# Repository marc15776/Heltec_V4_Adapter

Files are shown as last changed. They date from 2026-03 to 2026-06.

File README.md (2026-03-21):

# Heltec LoRa V4 Adapter

This is a fork from [kiu/lofence](https://github.com/kiu/lofence)

I used the the resistor and opamp concept to use  with the [Heltec LoRa V4](https://heltec.org/project/wifi-lora-32-v4/) adc input.
I dont need the microcontroller, LoRa chipset and battery management since that is already integrated on the Heltec V4 board.
I will probably use this in point to point mode with another Heltec board.

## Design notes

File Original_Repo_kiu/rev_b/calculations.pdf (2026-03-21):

Tabelle1

Seite 1

Ohm | 10000000 | 10000000 | 1000000 | 5800
Volt Drop | 5712,70791877 | 5712,707919 | 571,2707919 3,313370592884
Ohm Calc | 10050000 | 10070000 | 997000 | 5807,175
Ohm Real | 10050000 | 10070000 | 997000 | 5720
Volt Real | 5709,49195937 | 5720,854132 | 566,4043267 3,249581493293
| Standby | Measure | Transmit
mA | 0,012 | 20 | 50
Minutes | 59 | 0,5 | 0,5
mAh | 0,0118 | 0,166666667 | 0,416666667
Battery mAh | 3000
| Hours | Days | Weeks | Months | Years
Runtime | 5040,89 | 210,04 | 30,01 | 7,50 | 0,63

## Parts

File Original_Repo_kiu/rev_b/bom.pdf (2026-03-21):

BOM
Symbol | Description | Req | +VAT | Price | Price (sum) | Provider | ID
| | | | MOQ 10
U1 | Opamp TLV9062 | 1 | 19 | 0,45 € | 0,54 € | http://www.mouser.de | 595-TLV9062IDR
(U2) | LDO MIC5504 | 0 | 19 | 0,10 € | 0,00 € | http://www.mouser.de | 998-MIC5504-3.3YM5TR
U3 | ATMega328PB-AU | 1 | 19 | 1,19 € | 1,42 € | http://www.mouser.de | 556-ATMEGA328PB-AU
U4 | RN2483 | 1 | 19 | 11,34 € | 13,49 € | http://www.mouser.de | 579-RN2483A-I/RM105
U5 | MCP1253-33X50 | 1 | 19 | 1,21 € | 1,44 € | http://www.mouser.de | 579-MCP1253T33X50IMS
J3 | 2x03 | 1 | 19 | 0,18 € | 0,21 € | http://www.mouser.de | 649-861400062YO2LF
J5 | 1x03 | 1 | 19 | 0,10 € | 0,11 € | http://www.mouser.de | 710-61300311121
J4, J6 | 1x04 | 2 | 19 | 0,14 € | 0,33 € | http://www.mouser.de | 710-61300411121
J7 | U.FL Straight Surface Mount Jack | 1 | 19 | 0,60 € | 0,72 € | http://www.mouser.de | 712-CONUFL001-SMD
C12, (C2, C3) | 1uF X7R 0805 | 1 | 19 | 0,04 € | 0,05 € | http://www.mouser.de | 963-EMK212B7105KG-T
C4 | 10uF 4x5.5 | 1 | 19 | 0,16 € | 0,19 € | http://www.mouser.de | 710-865080440002
C1, C5, C6, C7, C8, C9, C10, C11 | 100nF | 8 | 19 | 0,04 € | 0,37 € | http://www.mouser.de | 710-885012207098
C13, C14 | 10uF X7R 1206 | 2 | 19 | 0,12 € | 0,29 € | http://www.mouser.de | 963-LMK316B7106KL-T
R9 | 4k7 0805 | 1 | 19 | 0,04 € | 0,05 € | http://www.mouser.de | 667-ERJ-6ENF4701V
R5, R6 | 232R 0805 | 2 | 19 | 0,03 € | 0,08 € | http://www.mouser.de | 660-RK73H2ATTD2320F
R7, R10, R16, R17, R18, R21 | 100k 0805 | 6 | 19 | 0,03 € | 0,24 € | http://www.mouser.de | 71-RCG0805100KFKEA
R1, R2 | 10M 6kV 1W THT | 2 | 19 | 0,49 € | 1,16 € | http://www.mouser.de | 594-5073DM10M00J
R3 | 1M 700V | 1 | 19 | 0,28 € | 0,33 € | http://www.mouser.de | 594-5043DM1M000F
R4 | 5k76 0805 | 1 | 19 | 0,04 € | 0,04 € | http://www.mouser.de | 652-CR0805FX-5761ELF
R12, R19 | 1M 0805 | 2 | 19 | 0,07 € | 0,16 € | http://www.mouser.de | 71-RCA08051M00FKEA
R8, R11, R13, R14 | 60R 0805 | 4 | 19 | 0,04 € | 0,17 € | http://www.mouser.de | 652-CR0805FX-62R0ELF
R15 | 68R 0805 | 1 | 19 | 0,01 € | 0,02 € | http://www.mouser.de | 652-CR0805FX-68R0ELF
R20 | 47R 0805 | 1 | 19 | 0,01 € | 0,02 € | http://www.mouser.de | 652-CR0805FX-47R0ELF
D2, D8 | BAV70LT3G | 2 | 19 | 0,08 € | 0,19 € | http://www.mouser.de | 863-BAV70LT3G
D1 | Schottky Diode | 1 | 19 | 0,35 € | 0,42 € | http://www.mouser.de | 863-MBRA210LT3G
D3, D5 | LED Green 0805 2.10V | 2 | 19 | 0,15 € | 0,37 € | http://www.mouser.de | 604-APT2012CGCK
D4, D6 | LED Orange 0805 2.10V | 2 | 19 | 0,15 € | 0,35 € | http://www.mouser.de | 604-APT2012SECK
D7 | LED Red 0805 1.95V | 1 | 19 | 0,15 € | 0,18 € | http://www.mouser.de | 604-APHCM2012SURCK
Y1 | 32768hz | 1 | 19 | 0,18 € | 0,21 € | http://www.mouser.de | 449-LFXTAL002996BULK
BT1 | 18650 Battery Holder THT | 1 | 19 | 2,15 € | 2,56 € | http://www.mouser.de | 534-1043
SW1 | Pushbutton | 1 | 19 | 0,48 € | 0,57 € | http://www.mouser.de | 612-LL3301FF065QJ
- | Antenna 868Mhz | 1 | 19 | 2,56 € | 3,05 € | https://aliexpress.com | 32972870968
- | SMA/F.UL Pigtail | 1 | 0 | 1,29 € | 1,29 € | https://aliexpress.com | 32809523843
- | Binding Post Red | 1 | 19 | 0,31 € | 0,36 € | http://www.mouser.de | 474-PRT-09739
- | Binding Post Black | 1 | 19 | 0,31 € | 0,36 € | http://www.mouser.de | 474-PRT-09740
- | IP67 Enclosure 1555J2F17GY | 1 | 0 | 13,22 € | 13,22 € | http://www.conrad.de | 536525 – 62
- | Screw 2,9x6.5 | 6 | 0 | 0,07 € | 0,39 € | http://www.amazon.de | B01CLLUIJI
- | 18650 Battery 3350 mAh (Not recommended!) | 0 | 0 | 9,45 € | 0,00 € | B07NZVXJSP
- | PCB 130x78 | 1 | 0 | 1,60 € | 1,60 € | -

SUM
46,53 €
465,28 €

https://www.amazon.de

http://jlcpcb.com

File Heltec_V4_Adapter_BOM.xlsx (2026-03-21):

Index | Hersteller-Teilenummer | Beschreibung | Menge | Digi-Key-Teilenr. | Stückpreis | Gesamtpreis | Datenblatt | Original-Teilenummern | Abbildung
1 | BAT54S | DIODE ARR SCHOTT 30V 200MA SOT23 | 10 | 5399-BAT54SCT-ND | $0.04 | $0.42 | https://mm.digikey.com/Volume0/opasdata/d220001/medias/docus/6778/5399_BAT54S%20SOT-23.PDF | 5399-BAT54STR-ND | https://mm.digikey.com/Volume0/opasdata/d220001/derivates/6/003/232/010/1801%7ESOT23-3%7E%7E3-View-2_web%28640x640%29.jpg
2 | CRCW08051M00FKEA | RES SMD 1M OHM 1% 1/4W 0805 | 10 | 541-1.00MCCT-ND | $0.04 | $0.41 | https://www.vishay.com/docs/20035/dcrcwe3.pdf | 541-1.00MCTR-ND | https://mm.digikey.com/Volume0/opasdata/d220001/medias/images/4322/cut-tape-render.jpg
3 | KGM21NR71A104JT | CAP CER 0.1UF 10V X7R 0805 | 10 | 478-KGM21NR71A104JTCT-ND | $0.16 | $1.64 | https://datasheets.kyocera-avx.com/KGM_X7R.pdf | 478-KGM21NR71A104JTTR-ND | https://mm.digikey.com/Volume0/opasdata/d220001/derivates/6/003/240/124/MFG_478_X7R_0805-%282012-Metric%29_web%28640x640%29.jpg
4 | CRCW080510K0FKEA | RES SMD 10K OHM 1% 1/4W 0805 | 10 | 541-10.0KCCT-ND | $0.04 | $0.41 | https://www.vishay.com/docs/20035/dcrcwe3.pdf | 541-10.0KCTR-ND | https://mm.digikey.com/Volume0/opasdata/d220001/medias/images/4322/cut-tape-render.jpg
5 | SMAJ5.0CA | TVS DIODE 5VWM 9.2VC DO214AC | 5 | SMAJ5.0CALFCT-ND | $0.31 | $1.55 | https://www.littelfuse.com/assetdocs/tvs-diodes-smaj-datasheet?assetguid=13c2a823-03b8-4d1f-9ddc-9b44670aed9d | SMAJ5.0CALFTR-ND | https://mm.digikey.com/Volume0/opasdata/d220001/medias/images/4828/118%7EDO214AC%28SMA%29%7E%7E2.JPG
6 | CRCW08055K10FKEA | RES SMD 5.1K OHM 1% 1/4W 0805 | 10 | 541-5.10KCCT-ND | $0.04 | $0.41 | https://www.vishay.com/docs/20035/dcrcwe3.pdf | 541-5.10KCTR-ND | https://mm.digikey.com/Volume0/opasdata/d220001/medias/images/4849/541_CRCW-0805-%282125metric%29.jpg
7 | CHV1206-JW-105ELF | RES SMD 1M OHM 5% 1/4W 1206 | 10 | CHV1206-JW-105ELFCT-ND | $0.07 | $0.71 | https://www.bourns.com/docs/product-datasheets/chv.pdf | CHV1206-JW-105ELFTR-ND | https://mm.digikey.com/Volume0/opasdata/d220001/medias/images/15/1206%283216_Metric%29.jpg
8 | HHV1WSJT-73-10M | RES 10M OHM 5% 1W AXIAL | 5 | 13-HHV1WSJT-73-10MCT-ND | $0.43 | $2.15 | https://yageogroup.com/content/datasheet/asset/file/YAGEO-HHV_DATASHEET | 13-HHV1WSJT-73-10MTB-ND | https://mm.digikey.com/Volume0/opasdata/d220001/medias/images/2483/10m-Ohm-Axial-5%25-HHV.jpg
9 | 1554E2GYCL | BOX PC GRAY/CLR 3.54"L X 3.54"W | 1 | HM1793-ND | $24.02 | $24.02 | https://www.hammfg.com/electronics/small-case/plastic/1554.pdf | HM1793-ND | https://mm.digikey.com/Volume0/opasdata/d220001/medias/images/951/MFG_1554E2GYCL.jpg

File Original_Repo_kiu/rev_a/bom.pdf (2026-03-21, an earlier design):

BOM

Page 1

Symbol | Description | Req | +VAT | Price | Price (sum) | Provider | ID
| | | | MOQ 10
U1 | ATMega328PB-AU | 1 | 19 | 1,19 € | 1,42 € | http://www.mouser.de | 556-ATMEGA328PB-AU
U2 | LDO MIC5504 | 1 | 19 | 0,10 € | 0,11 € | http://www.mouser.de | 998-MIC5504-3.3YM5TR
U3 | RN2483 | 1 | 19 | 11,34 € | 13,49 € | http://www.mouser.de | 579-RN2483A-I/RM104
U4 | Opamp TLV9062 | 1 | 19 | 0,45 € | 0,54 € | http://www.mouser.de | 595-TLV9062IDR
J1 | 2x03 | 1 | 19 | 0,18 € | 0,21 € | http://www.mouser.de | 649-861400062YO2LF
J2 | 1x02 | 1 | 19 | 0,07 € | 0,08 € | http://www.mouser.de | 649-861400021YO2LF
J3 | 2x02 | 1 | 19 | 0,12 € | 0,15 € | http://www.mouser.de | 649-86140042YO2319LF
J6 | 1x04 | 1 | 19 | 0,14 € | 0,16 € | http://www.mouser.de | 710-61300411121
C2, C3 | 1uF X7R 0805 | 2 | 19 | 0,11 € | 0,27 € | http://www.mouser.de | 81-GRM21BR71C105JA1K
C5, C10 | 10uF 4x5.5 | 2 | 19 | 0,16 € | 0,37 € | http://www.mouser.de | 710-865080440002
C1, C4, C9, C11, C12, C13, C16, C17 | 100nF | 8 | 19 | 0,04 € | 0,37 € | http://www.mouser.de | 710-885012207098
R2 | 4k7 0805 | 1 | 19 | 0,04 € | 0,05 € | http://www.mouser.de | 667-ERJ-6ENF4701V
R3, R4 | 232R 0805 | 2 | 19 | 0,03 € | 0,06 € | http://www.mouser.de | 660-RK73H2BTTD2320F
R5, R6, R7, R9, R10 | 100k 0805 | 5 | 19 | 0,03 € | 0,20 € | http://www.mouser.de | 71-RCG0805100KFKEA
R8, R11 | 10M 6kV 1W THT | 2 | 19 | 0,49 € | 1,16 € | http://www.mouser.de | 594-5073DM10M00J
R12 | 1M 700V | 1 | 19 | 0,28 € | 0,33 € | http://www.mouser.de | 594-5043DM1M000F
R13 | 5k76 0805 | 1 | 19 | 0,04 € | 0,04 € | http://www.mouser.de | 652-CR0805FX-5761ELF
R14, R15 | 1M 0805 | 2 | 19 | 0,07 € | 0,16 € | http://www.mouser.de | 71-RCA08051M00FKEA
D1, D2 | BAV70LT3G | 2 | 19 | 0,08 € | 0,19 € | 863-BAV70LT3G
L1 | 10uH 0805 | 1 | 19 | 0,06 € | 0,07 € | http://www.mouser.de | 963-LBR2012T100K
L2 | Ferrite 0805 220R 2A | 1 | 19 | 0,06 € | 0,07 € | http://www.mouser.de | 81-BLM21P221SG
Y1 | 32768hz | 1 | 19 | 0,18 € | 0,21 € | http://www.mouser.de | 449-LFXTAL002996BULK
BT1 | 18650 Battery Holder THT | 1 | 19 | 2,15 € | 2,56 € | http://www.mouser.de | 534-1043
- | Antenna 868Mhz | 1 | 19 | 6,03 € | 7,18 € | http://www.mouser.de | 815-CAQ190012-S868
- | Binding Post Red | 1 | 19 | 0,31 € | 0,36 € | http://www.mouser.de | 474-PRT-09739
- | Binding Post Black | 1 | 19 | 0,31 € | 0,36 € | http://www.mouser.de | 474-PRT-09740
- | IP67 Enclosure 1555J2F17GY | 1 | 0 | 13,22 € | 13,22 € | http://www.conrad.de | 536525 – 62
- | 18650 Battery 3350 mAh (No Protection Circuit, Amazon Link not recommended) | 1 | 0 | 9,45 € | 9,45 € | B07NZVXJSP
- | PCB 100x50 Red | 1 | 0 | 1,41 € | 1,41 € | -

SUM
54,26 €
542,64 €

http://www.mouser.de

https://www.amazon.de

http://www.seeedstudio.com

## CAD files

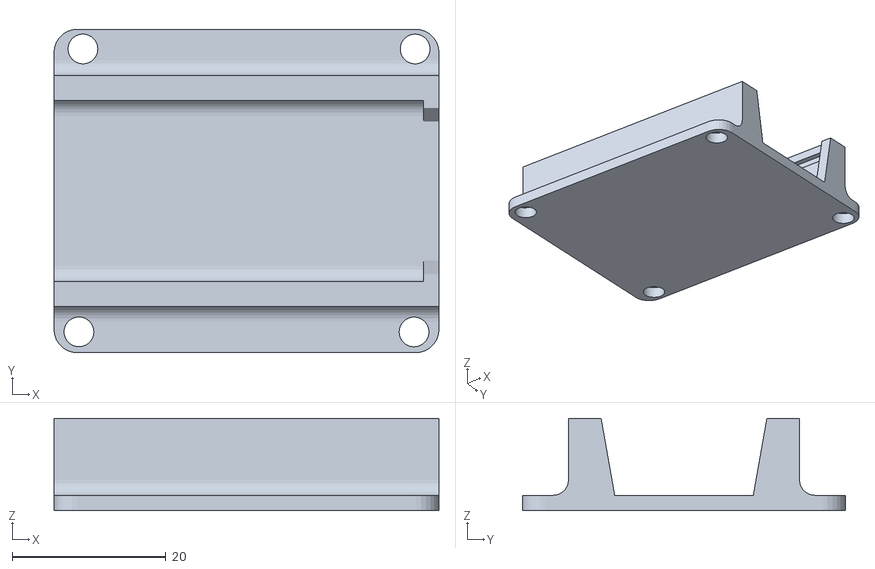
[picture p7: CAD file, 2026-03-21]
.stl/heltec_v4_stand-body-with-holesstl.stl
50.0 x 42.0 x 12.0

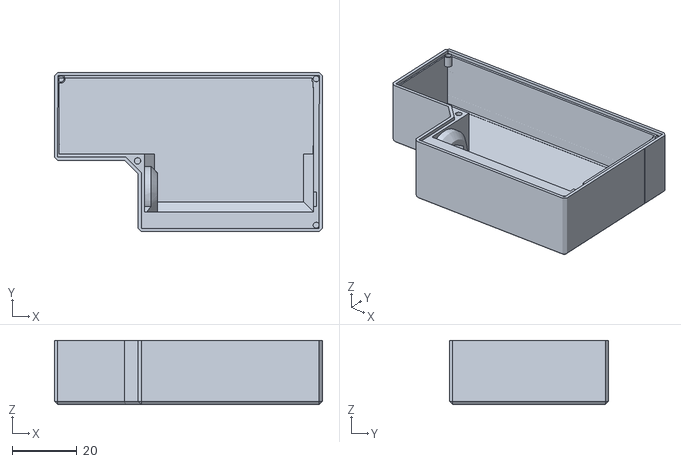
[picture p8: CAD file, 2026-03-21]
.stl/heltec_v4_with_18650_bracket_space_and_gps_bottom_v2.stl
82.9 x 49.2 x 19.9

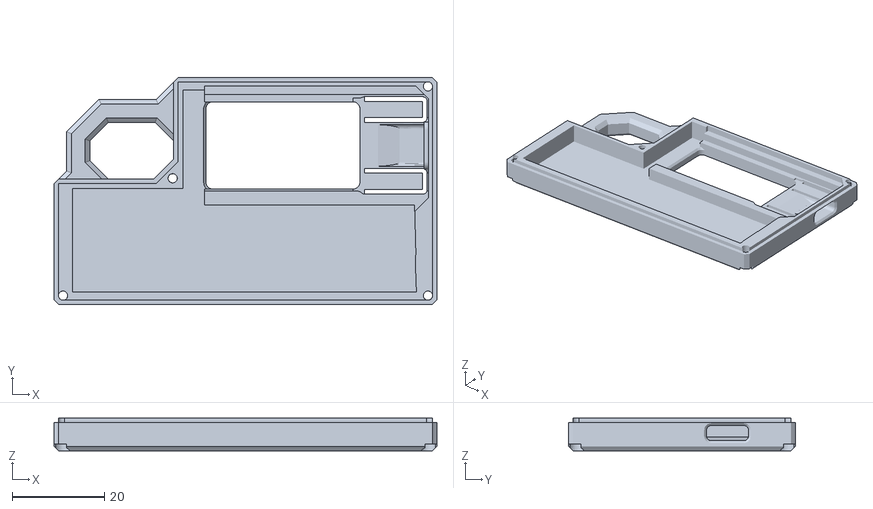
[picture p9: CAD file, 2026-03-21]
.stl/heltec_v4_with_18650_bracket_space_and_gps_v2.stl
82.9 x 49.2 x 7.10

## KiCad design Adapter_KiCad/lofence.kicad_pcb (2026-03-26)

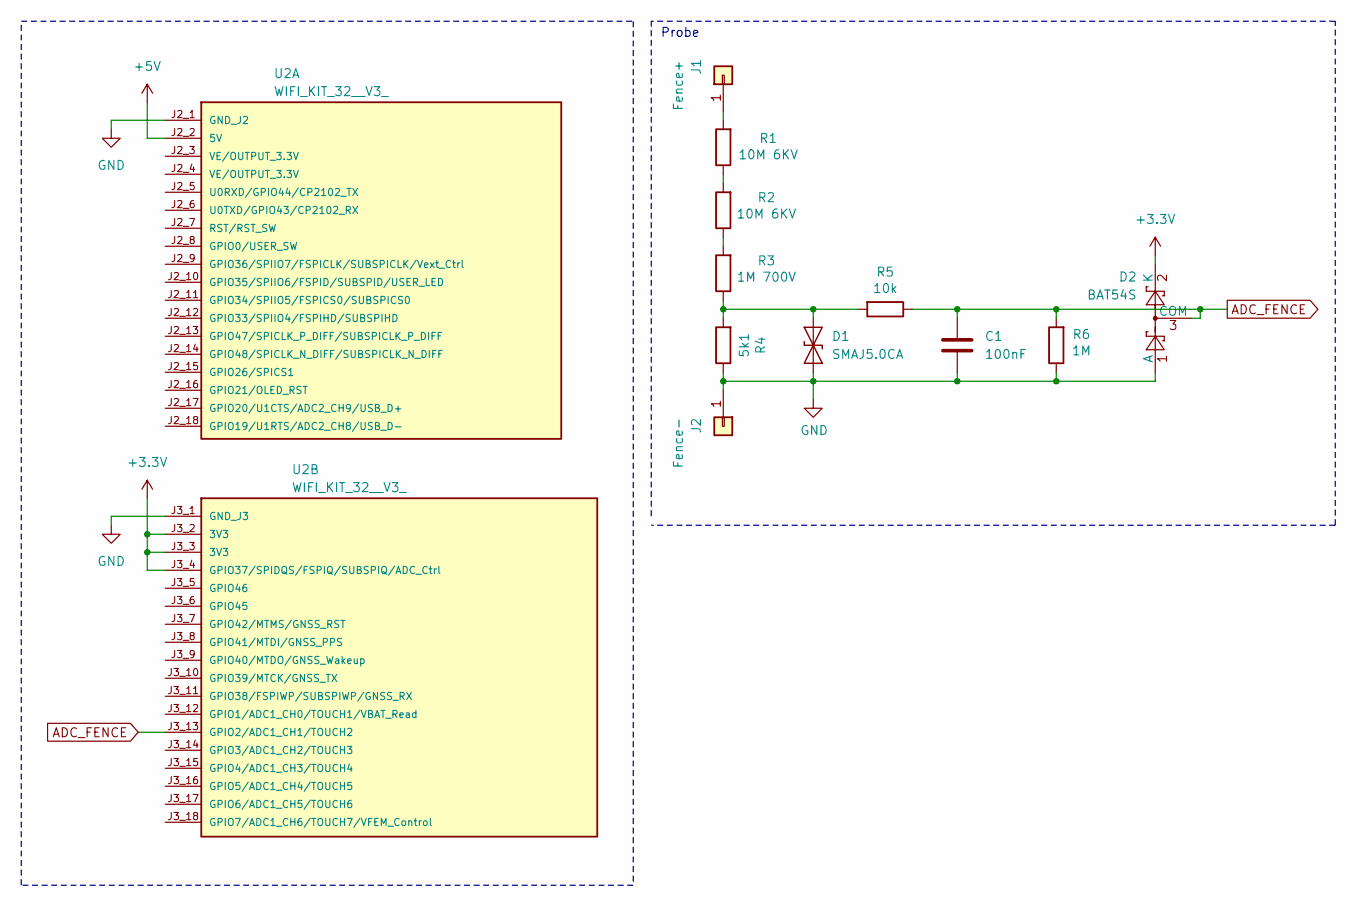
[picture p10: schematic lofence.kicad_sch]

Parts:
C1: 100nF; C_0805_2012Metric_Pad1.18x1.45mm_HandSolder
D1: SMAJ5.0CA; D_SMA
D2: BAT54S; SOT-23
J1: Fence+; Measurement_Point_Square-SMD-Pad_Big
J2: Fence-; Measurement_Point_Square-SMD-Pad_Big
R1, R2: 10M 6KV; R_Axial_DIN0414_L11.9mm_D4.5mm_P15.24mm_Horizontal
R3: 1M 700V; R_1206_3216Metric_Pad1.30x1.75mm_HandSolder
R4: 5k1; R_0805_2012Metric_Pad1.20x1.40mm_HandSolder
R5: 10k; R_0805_2012Metric_Pad1.20x1.40mm_HandSolder
R6: 1M; R_0805_2012Metric_Pad1.20x1.40mm_HandSolder
U2: WIFI_KIT_32__V3_; MODULE_WIFI_KIT_32__V3_; PARTREV Rev 1.1

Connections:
+3.3V: D2.2 (K), U2.J3_2 (3V3), U2.J3_3 (3V3), U2.J3_4 (GPIO37/SPIDQS/FSPIQ/SUBSPIQ/ADC_Ctrl)
+5V: U2.J2_2 (5V)
ADC_FENCE: C1.1, D2.3 (COM), R5.1, R6.2, U2.J3_13 (GPIO2/ADC1_CH1/TOUCH2)
GND: C1.2, D1.1 (A1), D2.1 (A), J2.1, R4.1, R6.1, U2.J2_1 (GND_J2), U2.J3_1 (GND_J3)
unnamed: D1.2 (A2), R3.1, R4.2, R5.2
unnamed: J1.1, R1.2
unnamed: R1.1, R2.2
unnamed: R2.1, R3.2

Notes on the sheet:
Probe

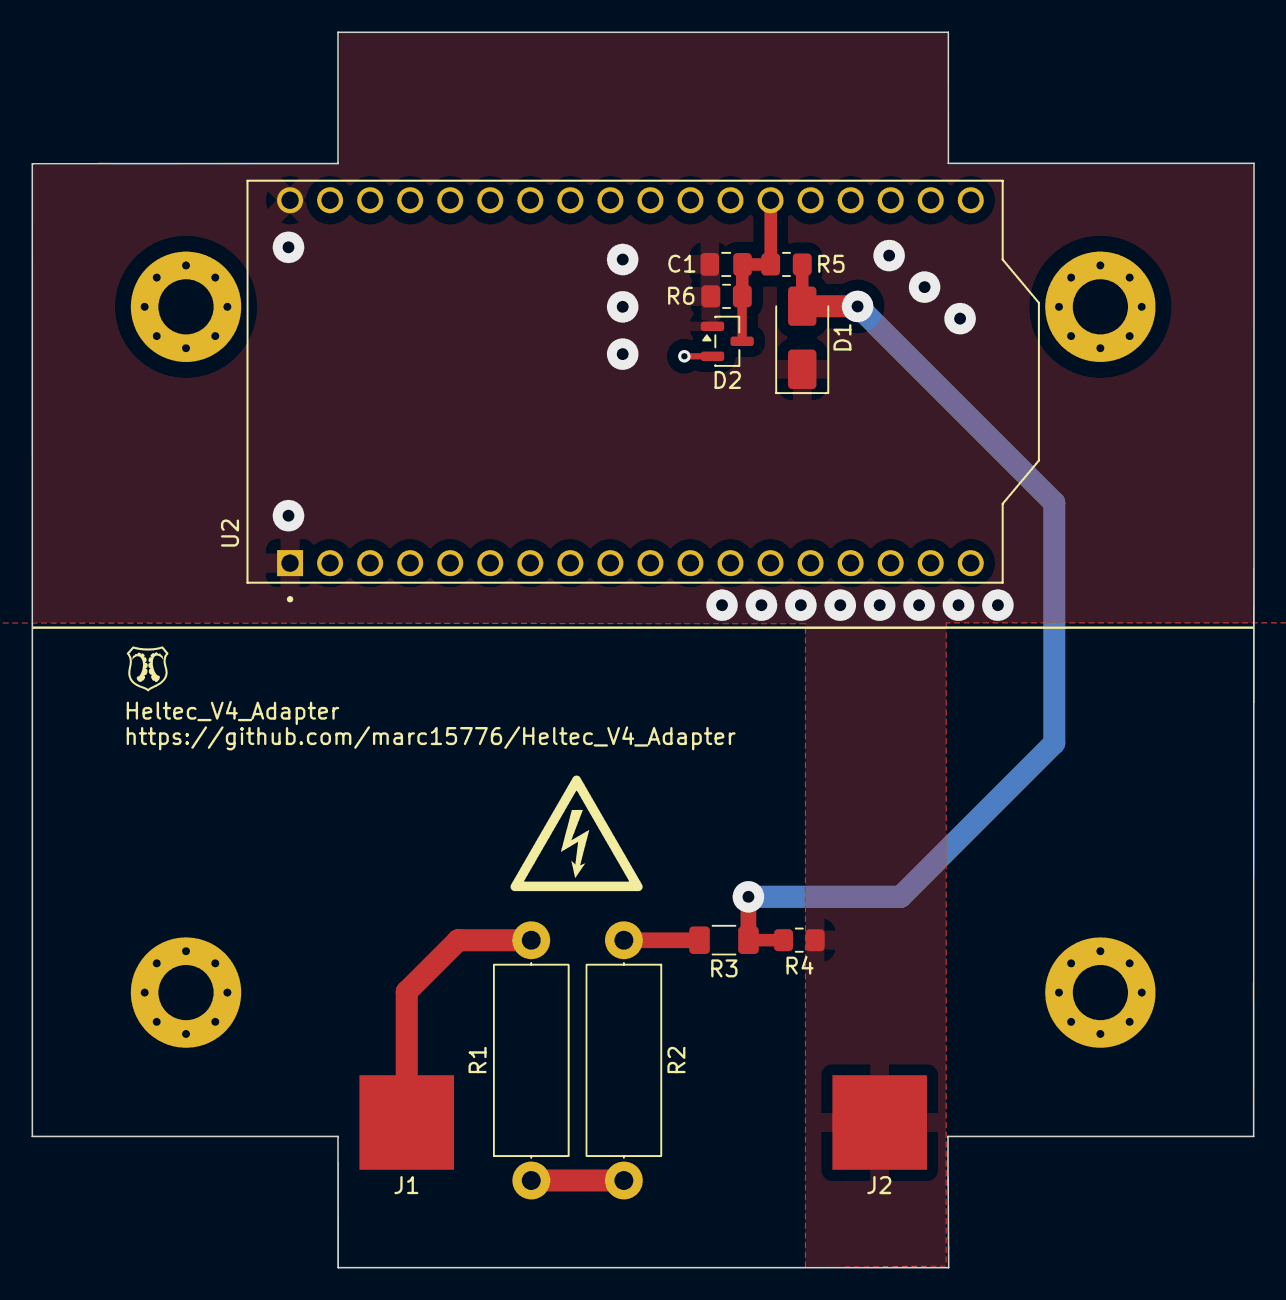
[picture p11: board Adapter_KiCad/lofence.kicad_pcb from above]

Board: 4 copper layers, 77.5 x 78.4 mm, 12 parts (0 on the bottom side), 7 nets.

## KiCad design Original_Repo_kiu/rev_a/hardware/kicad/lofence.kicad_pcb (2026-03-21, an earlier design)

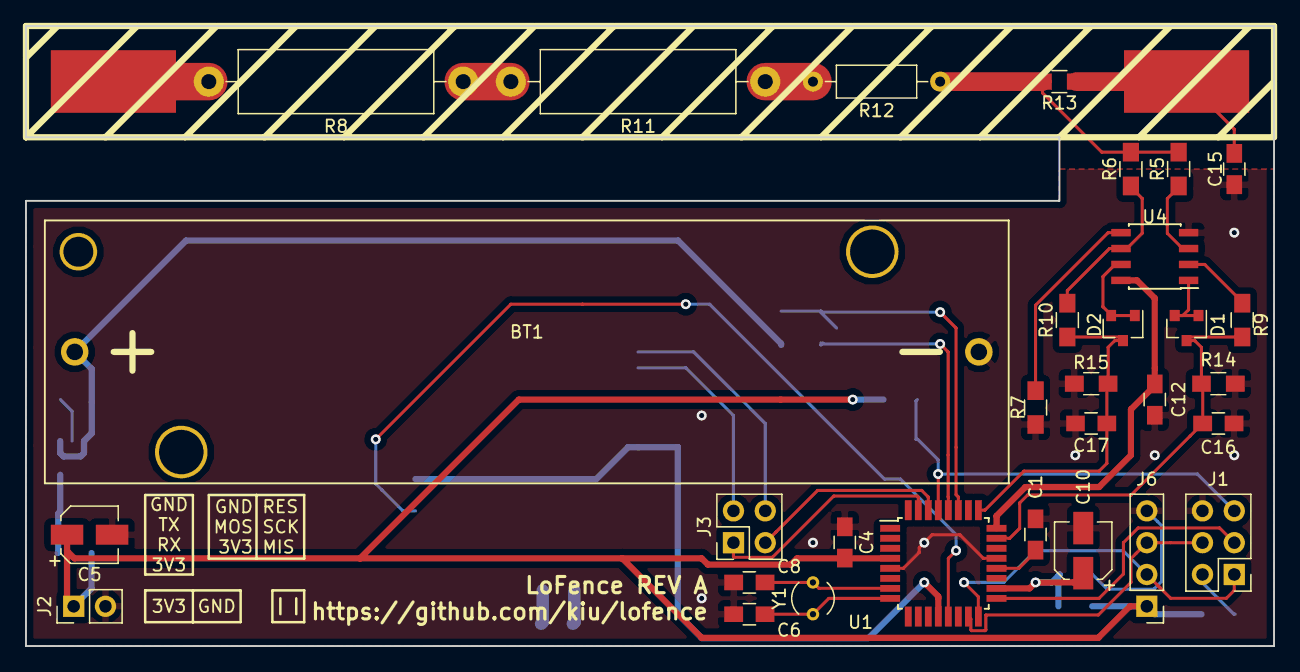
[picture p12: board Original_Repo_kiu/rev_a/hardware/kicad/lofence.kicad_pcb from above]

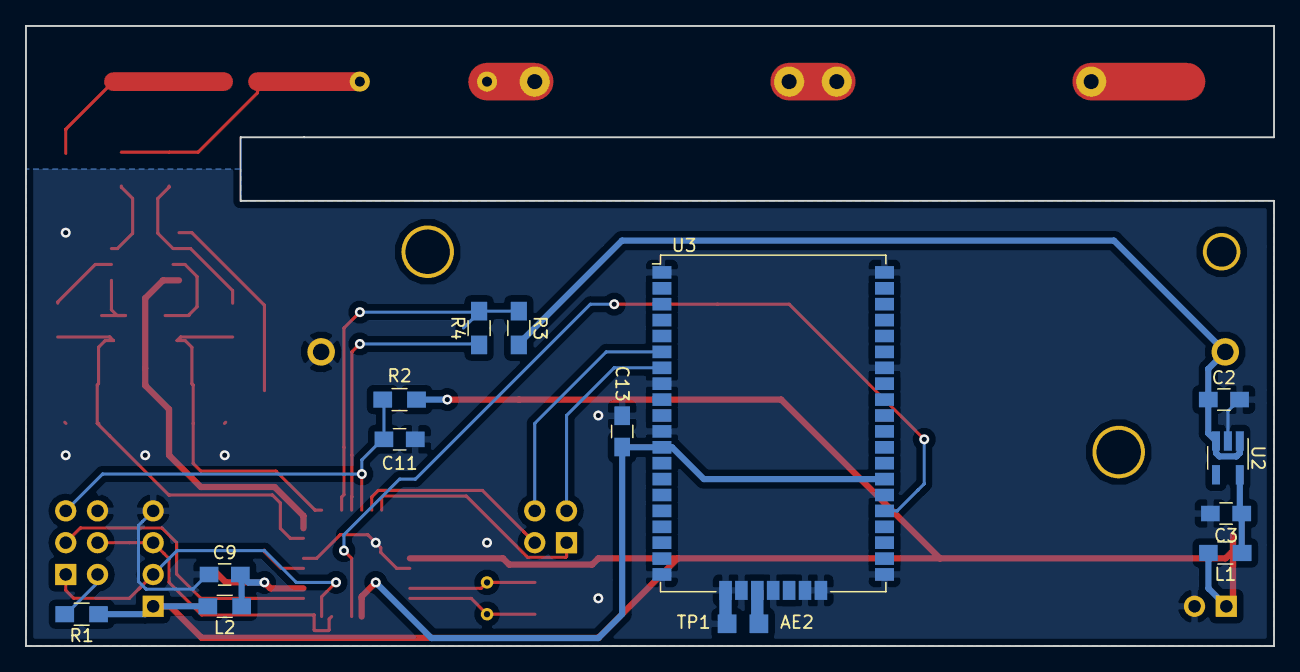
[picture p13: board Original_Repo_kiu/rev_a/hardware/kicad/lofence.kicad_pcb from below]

Board: 2 copper layers, 99.7 x 49.5 mm, 48 parts (15 on the bottom side), 36 nets.

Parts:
AE2: Antenna; Measurement_Point_Square-SMD-Pad_Small
BT1: Battery_Cell; 18650HolderTHT
C1, C4, C9, C11, C12, C13, C16, C17: 100nF; C_0805_HandSoldering
C2, C3: 1.0uF; C_0805_HandSoldering
C5, C10: 10uF; CP_Elec_4x5.7
C6, C8: 0pF; C_0805_HandSoldering
C15: 0nF; C_0805_HandSoldering
D1, D2: BAV70LT; SOT-23
J1: ISP; Pin_Header_Straight_2x03_Pitch2.54mm
J2: POWER; Pin_Header_Straight_1x02_Pitch2.54mm
J3: DEBUG RN2483; Pin_Header_Straight_2x02_Pitch2.54mm
J5: Fence+; SolderWirePad_single_SMD_5x10mm
J6: DEBUG RXTX; Pin_Header_Straight_1x04_Pitch2.54mm
J7: Fence-; SolderWirePad_single_SMD_5x10mm
L1: 10uH; R_0805_HandSoldering
L2: Ferrite_Bead; R_0805_HandSoldering
R1: 0R; R_0805_HandSoldering
R2: 4k7; R_0805_HandSoldering
R3, R4: 232R; R_0805_HandSoldering
R5, R6, R7, R9, R10: 100k; R_0805_HandSoldering
R8, R11: 10M 6KV; R_Axial_DIN0516_L15.5mm_D5.0mm_P20.32mm_Horizontal
R12: 1M 700V; R_Axial_DIN0207_L6.3mm_D2.5mm_P10.16mm_Horizontal
R13: 3k9; R_0805_HandSoldering
R14, R15: 1M; R_0805_HandSoldering
TP1: TestPoint; Measurement_Point_Square-SMD-Pad_Small
U1: ATmega328PB-AU; TQFP-32_7x7mm_Pitch0.8mm
U2: MIC5504-3.3YM5; SOT-23-5_HandSoldering
U3: RN2483
U4: Opamp_Dual_Generic; SOIC-8_3.9x4.9mm_Pitch1.27mm
Y1: 32768 Hz; Crystal_AT310_d3.0mm_l10.0mm_Vertical

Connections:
+3.3VADC: C9.2, C10.1, L2.1, U1.18
+3V3: C4.2, C5.1, J2.1, J6.1, L1.2, L2.2, R1.1, R2.1, U1.4
ADC+: C16.1, D1.3, R9.1, R14.2, U1.23
ADC-: C17.1, D2.3, R10.1, R15.2, U1.25
ADC_POWER: C12.2, U1.24, U4.8
BAT_ADC: R3.1, R4.2, U1.27
BAT_GND: R4.1, U1.28
BAT_VCC: BT1.1, C2.1, R3.2, U2.1, U2.3
GND: BT1.2, C1.2, C2.2, C3.2, C4.1, C5.2, C6.1, C8.1, C9.1, C10.2, C11.2, C12.1, C13.1, C15.2, C16.2, C17.2, J1.6, J2.2, J6.4, R7.1, R14.1, R15.1, TP1.1, U1.5, U1.21, U2.2, U3.1, U3.8, U3.11, U3.20, U3.21, U3.22, U3.24, U3.26, U3.27, U3.28, U3.33, U3.41, U3.47, U4.4
MCU_DBG_RX: J1.1, J6.2, U1.16
MCU_DBG_TX: J1.4, J6.3, U1.15
MCU_RESET: C11.1, J1.5, R2.2, U1.29
MCU_RX: J3.3, U1.30
MCU_SCK: J1.3, U1.17
MCU_TX: J3.1, U1.31
unnamed: AE2.1, U3.23
unnamed: C1.1, U1.20
unnamed: C3.1, L1.1, U2.5
unnamed: C6.2, U1.8, Y1.1
unnamed: C8.2, U1.7, Y1.2
unnamed: C15.1, J7.1, R13.1
unnamed: D1.1, D1.2, U4.1
unnamed: D2.1, D2.2, U4.7
unnamed: J1.2, R1.2
unnamed: J5.1, R8.2
unnamed: R5.1, U4.3
unnamed: R7.2, U4.5
unnamed: R9.2, U4.2
unnamed: R6.1, R10.2, U4.6
unnamed: R11.1, R12.2
unnamed: R8.1, R11.2
PROBE: R5.2, R6.2, R12.1, R13.2
RN_POWER: C13.2, U1.12, U3.12, U3.34
RN_RESET: U1.13, U3.32
RN_RX: J3.2, U3.7
RN_TX: J3.4, U3.6

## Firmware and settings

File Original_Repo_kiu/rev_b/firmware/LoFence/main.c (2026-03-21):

#include <atmel_start.h>
#include <util/delay.h>
#include <string.h>
#include <stdio.h>
#include "main.h"

#define MAX(x, y) (((x) > (y)) ? (x) : (y))
#define MIN(x, y) (((x) < (y)) ? (x) : (y))

volatile uint32_t seconds = 0;

volatile uint8_t adc_clear = 0;
volatile uint8_t adc_max = 0;
volatile uint8_t adc_min = 0;
//volatile uint32_t adc_samples = 0;
uint8_t adc_val = 0;

char buffer_dbg [256];
char buffer_rn [256];
	
uint16_t volt_bat = 0;
uint16_t volt_fence_plus = 0;
uint16_t volt_fence_minus = 0;

uint16_t rounds = 0;

// ----------------------------------------------------------------------------------------------

ISR(TIMER2_OVF_vect) {
	// see https://www.mikrocontroller.net/articles/AVR-GCC-Tutorial/Die_Timer_und_Z%C3%A4hler_des_AVR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
	TCCR2B = TCCR2B;
	seconds++;	
	LED_CLK_toggle_level();
	while(ASSR & ((1<<TCN2UB) | (1<<OCR2AUB) | (1<<OCR2BUB) | (1<<TCR2AUB) | (1<<TCR2BUB)));
}

ISR(ADC_vect) {
	adc_val = ADCH;
	if (adc_clear == 1) {
		adc_clear = 0;
		adc_max = 0x00;
		adc_min = 0xFF;
//		adc_samples = 0;
	}
	adc_max = MAX(adc_max, adc_val);
	adc_min = MIN(adc_min, adc_val);
//	adc_samples++;
}

// ----------------------------------------------------------------------------------------------

void adc_init() {
	#ifdef DEBUG
	debug("ADC initialization\r\n");
	#endif

	PRR0 &= ~(1 << PRADC); // Enable
	
	DIDR0 = (1 << ADC0D) | (1 << ADC2D) | (1 << ADC4D); // Disable input buffer
	
	ADMUX = 0x00;
	ADMUX |= (0 << REFS1) | (1 << REFS0); // AVCC with external capacitor at AREF pin
	ADMUX |= (1 << ADLAR); // Left Adjust Result: enabled
	
	ADCSRA = 0x00;
	ADCSRA |= (1 << ADATE); // Auto Trigger: enabled
	ADCSRA |= (1 << ADIE); // ADC Interrupt: enabled
	
	// Safe range: 50khz - 200khz
	//ADCSRA |= (1 << ADPS2) | (0 << ADPS1) | (0 << ADPS0); // 100  16 500khz
	ADCSRA |= (1 << ADPS2) | (0 << ADPS1) | (1 << ADPS0); // 101  32 250khz
	//ADCSRA |= (1 << ADPS2) | (1 << ADPS1) | (0 << ADPS0); // 110  64 125khz
	//ADCSRA |= (1 << ADPS2) | (1 << ADPS1) | (1 << ADPS0); // 111 128  62khz
	
	ADCSRB = 0x00;
	ADCSRB |= (0 << ADTS2) | (0 << ADTS1) | (0 << ADTS0); // Free Running mode
	ADCSRB |= (0 << ACME); // Analog Comparator Multiplexer: disabled

	ACSR |= (1 << ACD); // Disable Comparator

	ADCSRA &= ~(1 << ADEN); // Disable ADC
	PRR0 |= (1 << PRADC); // Disable ADC
	
	#ifdef DEBUG
	debug("\r\n");
	#endif
}

void rn2483_init_error() {
	#ifdef DEBUG
	debug("Aborting initialization due to unexpected response\r\n");
	#endif

	rn2483_tx("sys sleep 86400000\r\n");
	
	while(1) {
		LED_TX_set_level(true);
		_delay_ms(200);
		LED_TX_set_level(false);
		_delay_ms(200);
	}
}

void rn2483_init() {
	#ifdef DEBUG
	debug("RN2483 initialization\r\n");
	#endif

	// Reset RN2483
	RN_RESET_set_level(false);
	_delay_ms(1);
	RN_RESET_set_level(true);
	_delay_ms(1000);

	rn2483_break_and_baud();
	
	rn2483_tx("sys get ver\r\n");
	rn2483_rx();

	rn2483_tx("sys get hweui\r\n");
	rn2483_rx();

	#ifdef FACTORY_RESET
	rn2483_tx("sys factoryRESET\r\n");
	_delay_ms(5000);
	rn2483_break_and_baud();
	while(1) {
		rn2483_rx();
	}
	#endif
	
	rn2483_tx("mac set adr on\r\n");
	rn2483_rx();

	sprintf (buffer_rn, "mac set devaddr %s\r\n", devAddr);
	rn2483_tx(buffer_rn);
	rn2483_rx();
	if (strcmp(buffer_rn, "ok\r\n") != 0) {
		rn2483_init_error();
		return;
	}

	sprintf (buffer_rn, "mac set nwkskey %s\r\n", nwkSKey);
	rn2483_tx(buffer_rn);
	rn2483_rx();
	if (strcmp(buffer_rn, "ok\r\n") != 0) {
		rn2483_init_error();
		return;
	}

	sprintf (buffer_rn, "mac set appskey %s\r\n", appSKey);
	rn2483_tx(buffer_rn);
	rn2483_rx();
	if (strcmp(buffer_rn, "ok\r\n") != 0) {
		rn2483_init_error();
		return;
	}
	
	rn2483_tx("sys sleep 86400000\r\n");

	#ifdef DEBUG
	debug("\r\n");
	#endif

}

// ----------------------------------------------------------------------------------------------

void power_save(uint32_t sec) {
	seconds = 0;
	sleep_enable();
	while (seconds <= sec) {
		sleep_mode();
	}
	sleep_disable();
}

void debug(char buf[]) {
	#ifdef DEBUG
	for (uint8_t i = 0; i < strlen(buf); i++) {
		while (!USART_1_is_tx_ready()) {}
		USART_1_write(buf[i]);
	}	
	while (USART_1_is_tx_busy()) {}
	#endif
}

void rn2483_break_and_baud() {
	#ifdef DEBUG
	debug ("RN2483 wakeup and baud change\r\n");
	#endif
	
	USART_0_disable();

	RN_TX_set_level(false);
	_delay_ms(5);
	RN_TX_set_level(true);

	USART_0_enable();
	
	while (!USART_0_is_tx_ready()) {}
	USART_0_write(0x55);
	
	rn2483_rx_clear();
}

void rn2483_tx(char buf[]) {
	#ifdef DEBUG
	debug("RN2483 TX: ");
	debug(buf);
	#endif
	
	for (uint8_t i = 0; i < strlen(buf); i++) {
		while (!USART_0_is_tx_ready()) {}
		USART_0_write(buf[i]);
	}
	while (USART_0_is_tx_busy()) {}
}

void rn2483_rx_clear() {
	#ifdef DEBUG
	debug("RN2483 RX clearing\r\n");
	#endif
		
	while(USART_0_is_rx_ready()) {
		while(USART_0_is_rx_ready()) {
			USART_0_read();
		}
		_delay_ms(100);
	}

}

void rn2483_rx() {
	char nc = 0x00;
	uint8_t len = 0;

	for (; len < 255; len++) {
		nc = USART_0_read();		
		buffer_rn[len] = nc;
		if (nc == '\n') {
			break;
		}
	}
	buffer_rn[len+1] = '\0';
	
	#ifdef DEBUG
	debug("RN2483 RX: ");
	debug(buffer_rn);
	#endif
}

// ----------------------------------------------------------------------------------------------

void measure() {
	LED_MSR_set_level(true);
	#ifdef DEBUG
	debug("Measuring\r\n");
	#endif
		
	// ----------------------------------------------------------------------------------------------

	PRR0 &= ~(1 << PRADC); // Enable ADC
	ADC_POWER_set_level(true);
	_delay_ms(1000);
		
	// ----------------------------------------------------------------------------------------------
		
	#ifdef DEBUG
	debug("Measuring battery: ");
	#endif

	BAT_GND_set_level(false);
	_delay_ms(1000);

	ADMUX = (ADMUX & 0xE0) | (1 << MUX2); // Pin 4
	ADCSRA |= (1 << ADEN);
	ADCSRA |= (1 << ADSC);
	adc_clear = 1;
	_delay_ms(500);
	ADCSRA &= ~(1 << ADEN);
	BAT_GND_set_level(true);

	volt_bat = (((330000/255*adc_min*2) - 0))/100;

	#ifdef DEBUG
	sprintf (buffer_dbg, "%d mV\r\n", volt_bat);
	debug(buffer_dbg);
	#endif

	// ----------------------------------------------------------------------------------------------

	#ifdef DEBUG
	debug("Measuring fence positive: ");
	#endif
				
	ADMUX = (ADMUX & 0xE0); // Pin 0
	ADCSRA |= (1 << ADEN);
	ADCSRA |= (1 << ADSC);
	adc_clear = 1;
	_delay_ms(MEASURE_MS);
	ADCSRA &= ~(1 << ADEN);

	volt_fence_plus = (12000/255*adc_max);

	#ifdef DEBUG
	sprintf (buffer_dbg, "%d V\r\n", volt_fence_plus);
	debug(buffer_dbg);
	#endif

	// ----------------------------------------------------------------------------------------------

	#ifdef DEBUG
	debug("Measuring fence negative: ");
	#endif

	ADMUX = (ADMUX & 0xE0) | (1 << MUX1); // Pin 2
	ADCSRA |= (1 << ADEN);
	ADCSRA |= (1 << ADSC);
	adc_clear = 1;
	_delay_ms(MEASURE_MS);
	ADCSRA &= ~(1 << ADEN);

	volt_fence_minus = (12000/255*adc_max);

	#ifdef DEBUG
	sprintf (buffer_dbg, "%d V\r\n", volt_fence_minus);
	debug(buffer_dbg);
	#endif

	// ----------------------------------------------------------------------------------------------

	ADC_POWER_set_level(false);
	PRR0 |= (1 << PRADC); // Disable ADC

	LED_MSR_set_level(false);
	#ifdef DEBUG
	debug("\r\n");
	#endif
}

void transmit_error() {
	#ifdef DEBUG
	debug("Aborting transmission due to unexpected response\r\n");
	#endif

	rn2483_tx("sys sleep 86400000\r\n");
	
	#ifdef DEBUG
	debug("\r\n");
	#endif
	
	for (uint8_t i = 0; i < 20; i++) {
		LED_TX_set_level(true);
		_delay_ms(200);
		LED_TX_set_level(false);
		_delay_ms(200);		
	}
}

void transmit() {
	LED_TX_set_level(true);
	#ifdef DEBUG
	debug("Transmitting\r\n");
	#endif

	rn2483_break_and_baud();

	rn2483_tx("mac join abp\r\n");
	rn2483_rx();
	if (strcmp(buffer_rn, "ok\r\n") != 0) {
		transmit_error();
		return;
	}
	rn2483_rx();
	if (strcmp(buffer_rn, "accepted\r\n") != 0) {
		transmit_error();
		return;
	}

	rn2483_tx("mac get upctr\r\n");
	rn2483_rx();

	rn2483_tx("mac set pwridx 1\r\n"); // 5 = low power, 1 = high power
	rn2483_rx();
	if (strcmp(buffer_rn, "ok\r\n") != 0) {
		transmit_error();
		return;
	}

	sprintf (buffer_rn, "mac tx uncnf 1 %04X%04X%04X%04X\r\n", rounds, volt_bat, volt_fence_plus, volt_fence_minus);
	rn2483_tx(buffer_rn);
	rn2483_rx();
	if (strcmp(buffer_rn, "ok\r\n") != 0) {
		transmit_error();
		return;	
	}
	rn2483_rx();
	if (strcmp(buffer_rn, "mac_tx_ok\r\n") != 0) {
		transmit_error();
		return;
	}

	rn2483_tx("mac save\r\n");
	rn2483_rx();		
	if (strcmp(buffer_rn, "ok\r\n") != 0) {
		transmit_error();
		return;
	}
	
	rn2483_tx("sys sleep 86400000\r\n");
	
	LED_TX_set_level(false);
	#ifdef DEBUG
	debug("\r\n");
	#endif
}

void pause() {
	LED_IDLE_set_level(true);
	#ifdef DEBUG
	sprintf (buffer_dbg, "Sleeping for %d seconds\r\n", INTERVAL_SECONDS);
	debug(buffer_dbg);
	_delay_ms(500);
	#endif
	
	power_save(INTERVAL_SECONDS);
	
	LED_IDLE_set_level(false);
	#ifdef DEBUG
	debug("\r\n");
	#endif
}

// ----------------------------------------------------------------------------------------------

int main(void) {

	atmel_start_init();

	LED_IDLE_set_level(true);
	LED_MSR_set_level(true);
	LED_TX_set_level(true);

	#ifdef DEBUG
	debug("\r\n");
	debug("\r\n");
	debug("LoFence REV B v0.4 by kiu\r\n");
	debug("https://github.com/kiu/lofence\r\n");
	debug("Lets get started!\r\n");
	debug("\r\n");
	#endif
	LED_IDLE_set_level(false);

	adc_init();
	LED_MSR_set_level(false);

	rn2483_init();			
	LED_TX_set_level(false);
		
	while (1) {
		
		#ifdef DEBUG
		sprintf(buffer_dbg, "Round: %u\r\n", rounds);
		debug(buffer_dbg);
		#endif
		
		measure();
		
		transmit();		
		
		pause();		

		rounds++;
	}
	
}

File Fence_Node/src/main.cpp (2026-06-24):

#include <Arduino.h>
#include <Wire.h>
#include <Adafruit_GFX.h>
#include <Adafruit_SSD1306.h>
#include "esp_sleep.h"

#define VEXT        36
#define OLED_RST    21
#define OLED_SDA    17
#define OLED_SCL    18

#define BUTTON_PIN  0

Adafruit_SSD1306 display(128, 64, &Wire, OLED_RST);

float homeBattery = 0.0;

// Platzhalter bis LoRa kommt
float fenceBattery = 4.02;
float fenceVoltage = 7420;

void readHomeBattery()
{
    pinMode(37, OUTPUT);
    digitalWrite(37, HIGH);

    delay(5);

    int bat_mv = analogReadMilliVolts(1);

    homeBattery = (bat_mv * 4.9f) / 1000.0f;
}

void drawScreen()
{
    display.clearDisplay();

    display.setTextColor(SSD1306_WHITE);

    display.setTextSize(1);

    display.setCursor(0, 0);
    display.print("HOME ");
    display.print(homeBattery, 2);
    display.println("V");

    display.setCursor(0, 12);
    display.print("ZAUN ");
    display.print(fenceBattery, 2);
    display.println("V");

    display.drawLine(0, 25, 127, 25, SSD1306_WHITE);

    display.setTextSize(2);

    display.setCursor(0, 38);
    display.print((int)fenceVoltage);
    display.print("V");

    display.display();
}

void powerOffOLED()
{
    display.clearDisplay();
    display.display();

    digitalWrite(VEXT, HIGH);
}

void goToSleep()
{
    Serial.println("Deep Sleep");

    powerOffOLED();

    delay(100);

    esp_sleep_enable_ext0_wakeup(
        GPIO_NUM_0,
        0
    );

    esp_deep_sleep_start();
}

void setup()
{
    Serial.begin(115200);

    delay(500);

    esp_sleep_wakeup_cause_t wakeup_reason =
        esp_sleep_get_wakeup_cause();

    if(wakeup_reason == ESP_SLEEP_WAKEUP_EXT0)
    {
        Serial.println("Wakeup durch Button");
    }
    else
    {
        Serial.println("Erster Start");
    }

    // OLED Strom EIN
    pinMode(VEXT, OUTPUT);
    digitalWrite(VEXT, LOW);

    delay(100);

    Wire.begin(OLED_SDA, OLED_SCL);

    if(!display.begin(SSD1306_SWITCHCAPVCC, 0x3C))
    {
        Serial.println("OLED Fehler");

        while(true)
        {
            delay(1000);
        }
    }

    analogReadResolution(12);

    readHomeBattery();

    drawScreen();

    Serial.print("Home Battery: ");
    Serial.println(homeBattery, 2);

    Serial.println("Anzeige 15 Sekunden");

    delay(15000);

    goToSleep();
}

void loop()
{
}

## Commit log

2026-03-21 First update
    [lofence.kicad_pcb, lofence.kicad_sch, lofence.sch]
2026-03-21 First changes in KiCad
    [heltec_v4_stand-body-with-holesstl.stl, heltec_v4_with_18650_bracket_space_and_gps_bottom_v2.stl, heltec_v4_with_18650_bracket_space_and_gps_v2.stl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]
2026-03-21 Finished PCB & Schematic
    [lofence.kicad_pcb, lofence.kicad_sch]
2026-03-21 Added BOM for PCB
    [Heltec_V4_Adapter_BOM.xlsx]
2026-03-26 Minor changes to pcb
    [lofence.kicad_pcb]
2026-03-26 Added Gerber files
    [lofence-+3_3V.gbr, lofence-B_Mask.gbr, lofence-B_Silkscreen.gbr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]
